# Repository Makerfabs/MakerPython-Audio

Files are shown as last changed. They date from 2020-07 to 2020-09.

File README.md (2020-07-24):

# MakerPython-Audio

```c++
/*
Version:		V2.0
Author:			UNKOWN
Create Date:	UNKOWN
Note:
	2020/7/24	v2.0: Rebuid readme,add pic. By Vincent
*/
```

[toc]

# Introduce

The MakePython Audio board uses the uDA1334 digital to analog converter (DAC), which converts I2S (not be confused with I2C) audio to an analog signal to drive speakers. The I2S Audioboard converts the digital audio signals using the I2S standard to an analog signal.

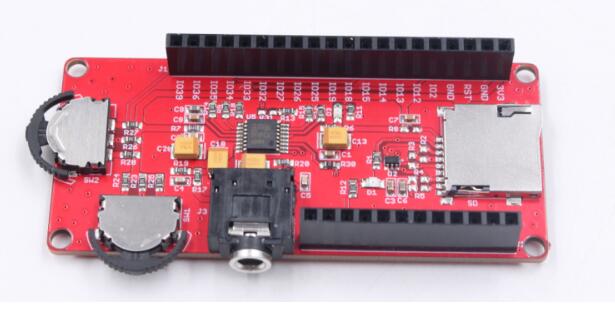
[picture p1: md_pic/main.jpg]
relay


- You can get one from: [MakePython_Audio](https://www.makerfabs.com/makepython-audio.html)

- Hardware and detailed instructions please visit Wiki page:  [MakePython_Audio Wiki](https://www.makerfabs.com/wiki/index.php?title=MakePython_Audio)

# Related Projects

## [Project_MakePython_Audio_Music](https://github.com/Makerfabs/Project_MakePython_Audio_Music)

- Make a music player by yourself.
- [YOUTUBE:MakePython Audio Music Play](https://www.youtube.com/watch?v=0urJ_uxfW0k&feature=youtu.be)

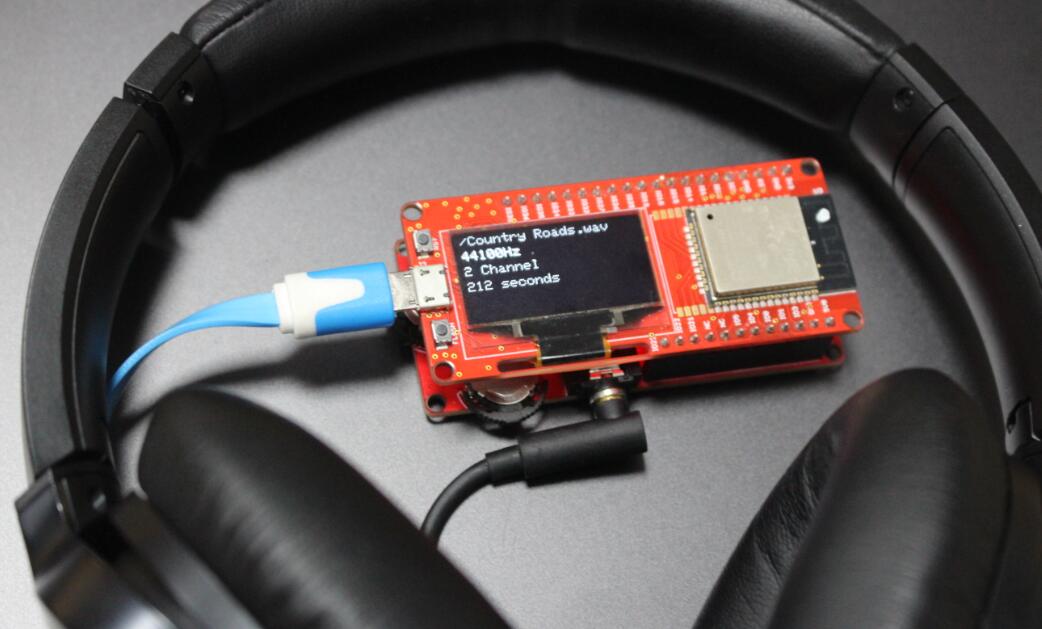
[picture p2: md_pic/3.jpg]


## [Project_TTS-Weather-Broadcast](https://github.com/Makerfabs/Project_TTS-Weather-Broadcast)

- Internet weather voice broadcast by TTS(Text to Speech).
- [YOUTUBE:TTS-Weather-Broadcast](https://youtu.be/00nAEQKYFV4)

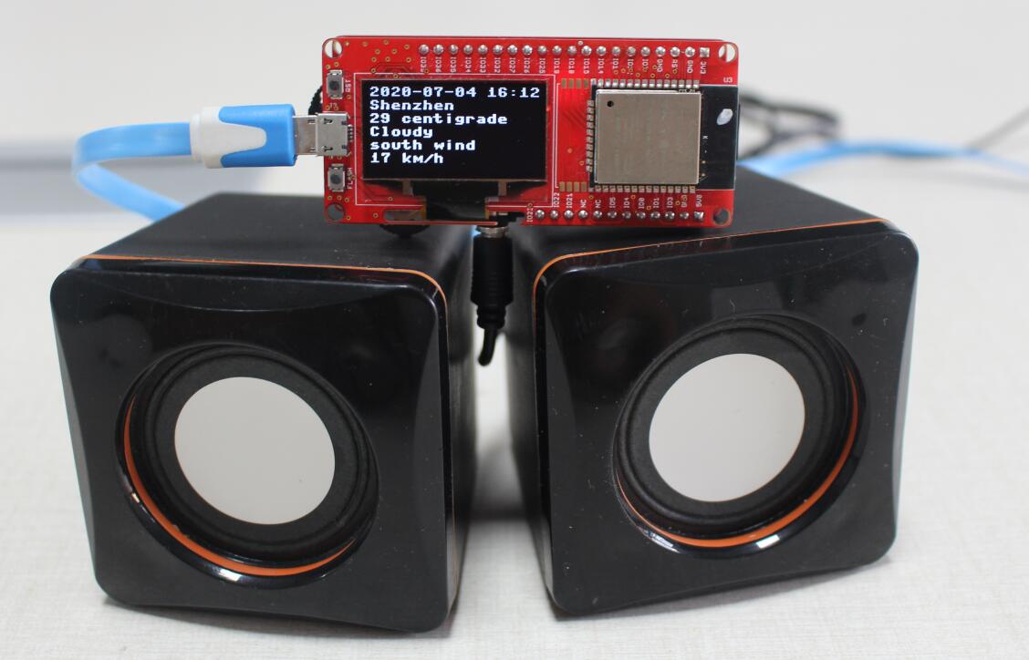
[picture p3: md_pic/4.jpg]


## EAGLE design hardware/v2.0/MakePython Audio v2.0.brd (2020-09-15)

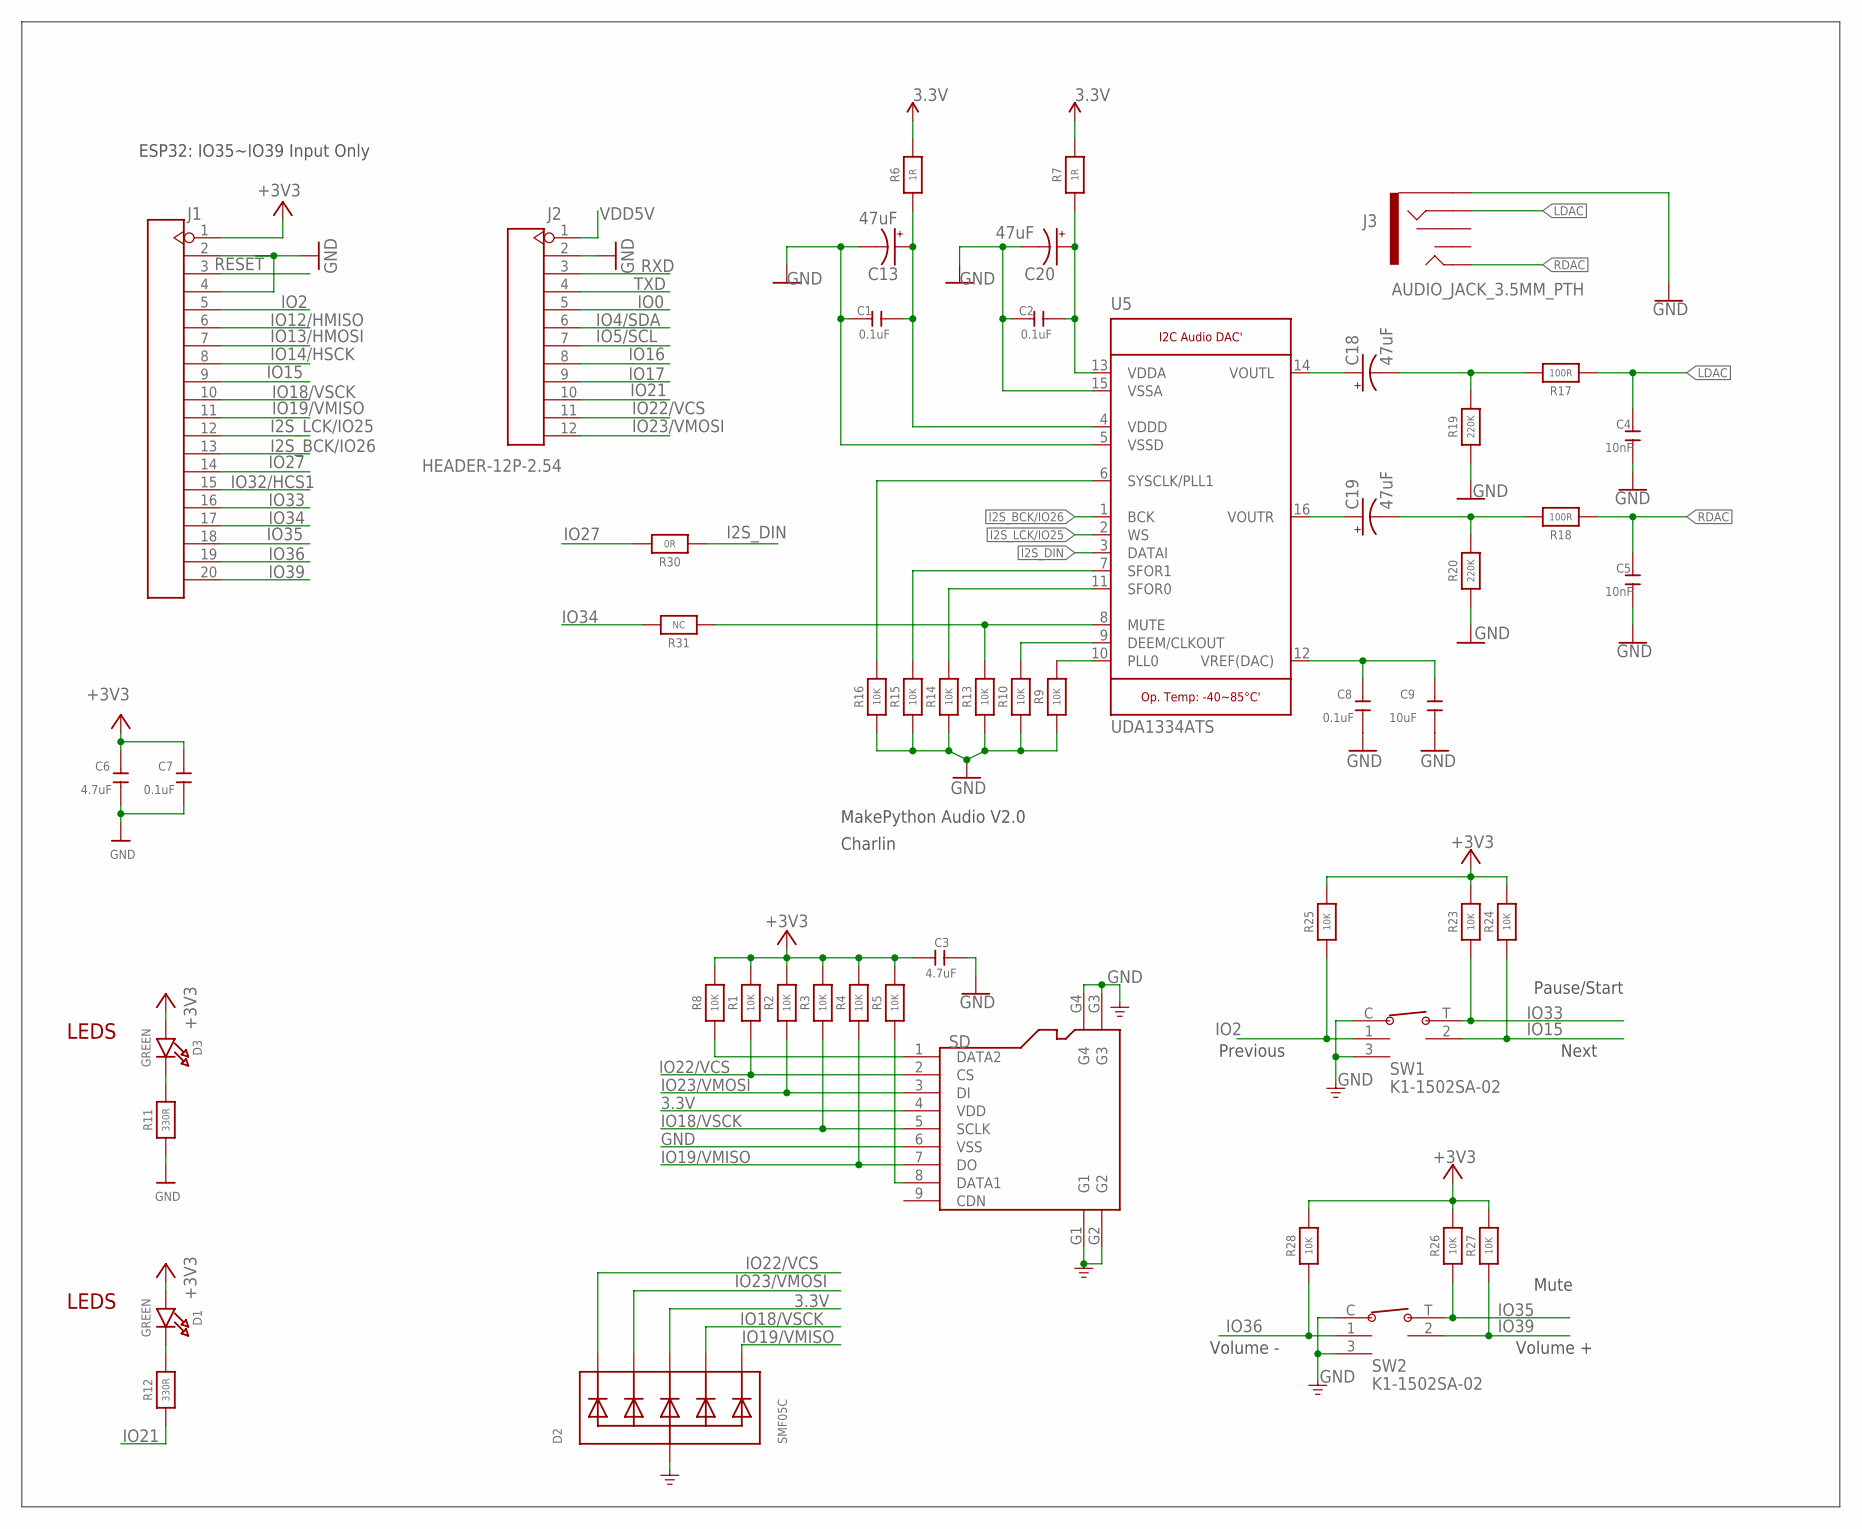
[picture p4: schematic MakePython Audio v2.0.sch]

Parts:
C1, C2, C7, C8: 0.1uF; DISCRETE_C0603
C3, C6: 4.7uF; DISCRETE_C0603
C4, C5: 10nF; DISCRETE_C0603
C9: 10uF; DISCRETE_C0603
C13, C18, C19, C20: 47uF; EIA3528
D1, D3: GREEN; CHIPLED_0805_NOOUTLINE
D2: SMF05C; SOT363
J1: HEADER-20P-2.54; 20P-2.54
J2: HEADER-12P-2.54; 12P-2.54
J3: AUDIO_JACK_3.5MM_PTH; AUDIO-JACK
R1, R2, R3, R4, R5, R8, R9, R10, R13, R14, R15, R16, R23, R24, R25, R26, R27, R28: 10K; 0603-NO
R6, R7: 1R; 0603-NO
R11, R12: 330R; 0603-NO
R17, R18: 100R; 0603-NO
R19, R20: 220K; 0603-NO
R30: 0R; 0603-NO
R31: NC; 0603-NO
SD: HOLDER-MICROSD-9P; 9P-SMD-W/-RING
SW1, SW2: K1-1502SA-02; SMD5-60P-1180L1170W
U5: UDA1334ATS; MICROBUILDER_SSOP16_4.4MM

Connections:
3.3V: C3.2, C6.2, C7.2, D1.A, D2.4 (C3), D3.A, J1.1, R1.2, R2.2, R3.2, R4.2, R5.2, R6.2, R7.2, R8.2, R23.2, R24.2, R25.2, R26.2, R27.2, R28.2, SD.4 (VDD)
GND: C1.2, C2.2, C3.1, C4.1, C5.1, C6.1, C7.1, C8.1, C9.1, C13.C (-), C20.C (-), D2.2 (A), J1.2, J1.4, J2.2, J3.SLEEVE, R9.1, R10.1, R11.1, R13.1, R14.1, R15.1, R16.1, R19.1, R20.1, SD.6 (VSS), SD.G1, SD.G2, SD.G3, SD.G4, SW1.3, SW1.C, SW2.3, SW2.C, U5.5 (VSSD), U5.15 (VSSA)
I2S_BCK/IO26: J1.13, U5.1 (BCK)
I2S_DIN: R30.1, U5.3 (DATAI)
I2S_LCK/IO25: J1.12, U5.2 (WS)
IO0: J2.5
IO2: J1.5, R25.1, SW1.1
IO4/SDA: J2.6
IO5/SCL: J2.7
IO12/HMISO: J1.6
IO13/HMOSI: J1.7
IO14/HSCK: J1.8
IO15: J1.9, R24.1, SW1.2
IO16: J2.8
IO17: J2.9
IO18/VSCK: D2.5 (C4), J1.10, R3.1, SD.5 (SCLK)
IO19/VMISO: D2.6 (C5), J1.11, R4.1, SD.7 (DO)
IO21: J2.10, R12.1
IO22/VCS: D2.1 (C1), J2.11, R1.1, SD.2 (CS)
IO23/VMOSI: D2.3 (C2), J2.12, R2.1, SD.3 (DI)
IO27: J1.14, R30.2
IO32/HCS1: J1.15
IO33: J1.16, R23.1, SW1.T
IO34: J1.17, R31.2
IO35: J1.18, R26.1, SW2.T
IO36: J1.19, R28.1, SW2.1
IO39: J1.20, R27.1, SW2.2
LDAC: C4.2, J3.RING, R17.1
unnamed: R8.1, SD.1 (DATA2)
unnamed: R5.1, SD.8 (DATA1)
unnamed: D1.C, R12.2
unnamed: D3.C, R11.2
unnamed: C18.A (+), U5.14 (VOUTL)
unnamed: C19.A (+), U5.16 (VOUTR)
unnamed: C18.C (-), R17.2, R19.2
unnamed: C19.C (-), R18.2, R20.2
unnamed: C2.1, C20.A (+), R7.1, U5.13 (VDDA)
unnamed: C1.1, C13.A (+), R6.1, U5.4 (VDDD)
unnamed: R16.2, U5.6 (SYSCLK/PLL1)
unnamed: R15.2, U5.7 (SFOR1)
unnamed: R14.2, U5.11 (SFOR0)
unnamed: R13.2, R31.1, U5.8 (MUTE)
unnamed: R10.2, U5.9 (DEEM/CLKOUT)
unnamed: R9.2, U5.10 (PLL0)
unnamed: C8.2, C9.2, U5.12 (VREF(DAC))
RDAC: C5.2, J3.TIP, R18.1
RESET: J1.3
RXD: J2.3
TXD: J2.4
VDD5V: J2.1

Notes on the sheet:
ESP32: IO35~IO39 Input Only
MakePython Audio V2.0
LEDS
Charlin
Previous
Next
Pause/Start
Volume +
Volume -
Mute

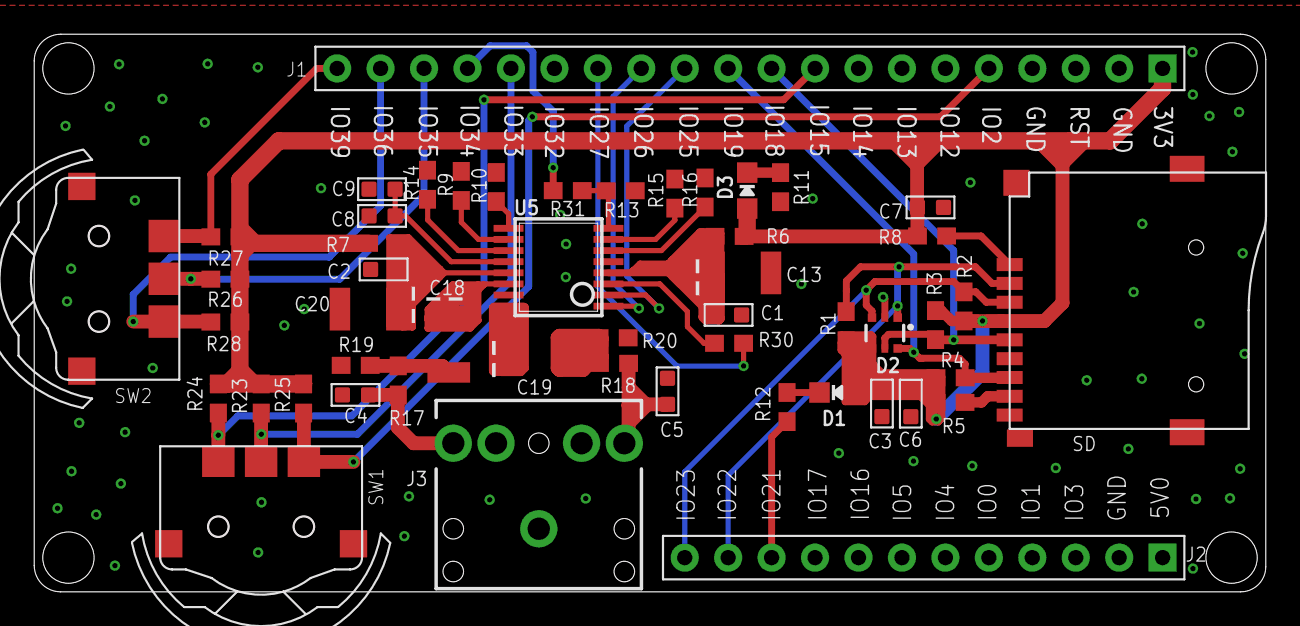
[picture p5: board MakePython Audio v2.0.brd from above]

Board: 2 copper layers, 72.0 x 32.6 mm, 52 parts (1 on the bottom side), 37 nets.

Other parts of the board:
U$1: MAKERFABS_0.3

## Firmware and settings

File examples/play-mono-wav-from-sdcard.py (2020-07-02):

# The MIT License (MIT)
# Copyright (c) 2020 Mike Teachman
# https://opensource.org/licenses/MIT

# Purpose:
# - read 16-bit audio samples from a mono formatted WAV file on SD card
# - write audio samples to an I2S amplifier or DAC module 
#
# Sample WAV files in wav_files folder:
#   "taunt-16k-16bits-mono.wav"
#   "taunt-16k-16bits-mono-12db.wav" (lower volume version)
#
# Hardware tested:
# - MAX98357A amplifier module (Adafruit I2S 3W Class D Amplifier Breakout)
# - PCM5102 stereo DAC module
#
# The WAV file will play continuously until a keyboard interrupt is detected or
# the ESP32 is reset
  
from machine import I2S
from machine import SDCard
from machine import Pin

#play-mono-wav-from-sdcard
#======= USER CONFIGURATION =======
WAV_FILE = 'taunt-16k-16bits-mono-12db.wav'
#WAV_FILE = 'LightMusic.wav'
SAMPLE_RATE_IN_HZ = 16000
#======= USER CONFIGURATION =======

bck_pin = Pin(26)
ws_pin = Pin(25)
sdout_pin = Pin(27)

# channelformat settings:
#     mono WAV:  channelformat=I2S.ONLY_LEFT
audio_out = I2S(
    I2S.NUM0, 
    bck=bck_pin, ws=ws_pin, sdout=sdout_pin, 
    standard=I2S.PHILIPS, 
    mode=I2S.MASTER_TX,
    dataformat=I2S.B16, 
    channelformat=I2S.ONLY_LEFT,
    samplerate=SAMPLE_RATE_IN_HZ,
    dmacount=10, dmalen=512)

# configure SD card
#   slot=2 configures SD card to use the SPI3 controller (VSPI), DMA channel = 2
#   slot=3 configures SD card to use the SPI2 controller (HSPI), DMA channel = 1
sd = SDCard(slot=3, sck=Pin(18), mosi=Pin(23), miso=Pin(19), cs=Pin(22))
uos.mount(sd, "/sd")
wav_file = '/sd/{}'.format(WAV_FILE)
wav = open(wav_file,'rb')

# advance to first byte of Data section in WAV file
pos = wav.seek(44) 

# allocate sample arrays
#   memoryview used to reduce heap allocation in while loop
wav_samples = bytearray(1024)
wav_samples_mv = memoryview(wav_samples)

print('Starting')
# continuously read audio samples from the WAV file 
# and write them to an I2S DAC
while True:
    try:
        num_read = wav.readinto(wav_samples_mv)
        num_written = 0
        # end of WAV file?
        if num_read == 0:
            # advance to first byte of Data section
            pos = wav.seek(44) 
        else:
            # loop until all samples are written to the I2S peripheral
            while num_written < num_read:
                num_written += audio_out.write(wav_samples_mv[num_written:num_read], timeout=0)
    except (KeyboardInterrupt, Exception) as e:
        print('caught exception {} {}'.format(type(e).__name__, e))
        break
    
wav.close()
uos.umount("/sd")
sd.deinit()
audio_out.deinit()
print('Done')

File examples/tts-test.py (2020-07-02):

from machine import I2S
from machine import Pin
import array
import speech


bck_pin = Pin(26)
ws_pin = Pin(25)
sdout_pin = Pin(27)


audio_out = I2S(I2S.NUM0,
                bck=bck_pin,
                ws=ws_pin,
                sdout=sdout_pin,
                standard=I2S.PHILIPS,
                mode=I2S.MASTER_TX,
                dataformat=I2S.B16,
                channelformat=I2S.ONLY_RIGHT,
                samplerate=16000,
                dmacount=16,
                dmalen=512)

a = bytearray(16000*8)
size = speech.say('the temperature is twenty six degree', a)
audio_out.write(a[:size])

def say(text):
    a = bytearray(16000*8)
    size = speech.say(text, a)
    audio_out.write(a[:size])
    
    
def close():
    audio_out.deinit()

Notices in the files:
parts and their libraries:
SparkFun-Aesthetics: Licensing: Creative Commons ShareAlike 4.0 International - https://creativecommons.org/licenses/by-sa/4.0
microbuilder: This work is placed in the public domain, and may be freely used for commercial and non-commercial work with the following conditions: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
